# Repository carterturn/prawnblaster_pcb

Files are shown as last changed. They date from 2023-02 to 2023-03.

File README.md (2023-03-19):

Prawnblaster PCB
================

Provides nice panel-mountable BNC connections and ground-isolated USB
for the Prawnblaster (<https://github.com/labscript-suite/prawnblaster>).

Loosely based on <https://github.com/TU-Darmstadt-APQ/Prawnblaster_Breakout>.

-Trigger input is buffered to allow 5V input without risk to Pi Pico.

-Output clocklines are buffered to drive at 5V (and avoid damage to Pi Pico from those lines floating to 5V).

-Clock input is buffered.

-Analog ADuM5000 used for 5V power isolation and Analog ADuM4160 used for USB isolation. Note that speed is fixed at high speed.

-Fits in 1U Bud box (slightly too tall, so upper panel bends slightly, but probably fine).

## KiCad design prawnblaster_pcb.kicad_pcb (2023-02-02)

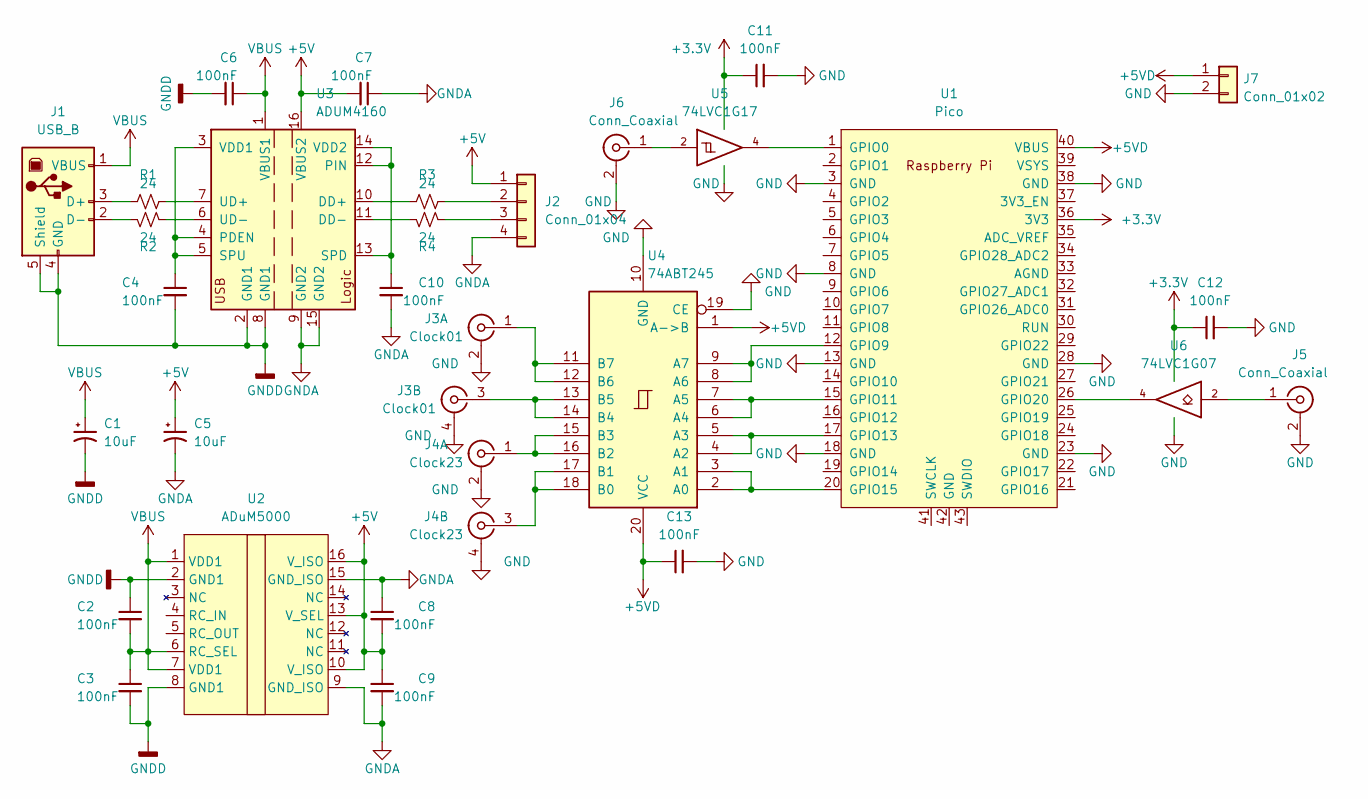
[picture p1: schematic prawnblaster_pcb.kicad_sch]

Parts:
C1, C5: 10uF; CP_Radial_D5.0mm_P2.00mm
C2, C3, C4, C6, C7, C8, C9, C10, C11, C12, C13: 100nF; C_0805_2012Metric
J1: USB_B; USB_B_OST_USB-B1HSxx_Horizontal
J2: Conn_01x04; PinHeader_1x04_P2.54mm_Vertical
J3: Clock01; BNC_Amphenol_031-6575_Horizontal
J4: Clock23; BNC_Amphenol_031-6575_Horizontal
J5, J6: Conn_Coaxial; BNC_Amphenol_B6252HB-NPP3G-50_Horizontal
J7: Conn_01x02; PinHeader_1x02_P2.54mm_Vertical
R1, R2, R3, R4: 24; R_0805_2012Metric
U1: Pico; RPi_Pico_SMD_TH
U2: ADuM5000; SOIC-16W_7.5x10.3mm_P1.27mm
U3: ADUM4160; SOIC-16W_7.5x10.3mm_P1.27mm
U4: 74ABT245; SOIC-20W_7.5x12.8mm_P1.27mm
U5: 74LVC1G17; SOT-23-5_HandSoldering
U6: 74LVC1G07; SOT-23-5_HandSoldering

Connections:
+3.3V: C11.1, C12.1, U1.36 (3V3), U5.5 (VCC), U6.5 (VCC)
+5V: C5.1, C7.2, C8.2, C9.1, J2.1, U2.10 (V_ISO), U2.13 (V_SEL), U2.16 (V_ISO), U3.16 (VBUS2)
+5VD: C13.1, J7.1, U1.40 (VBUS), U4.1 (A->B), U4.20 (VCC)
GND: C11.2, C12.2, C13.2, J3.2 (Ext1), J3.4 (Ext2), J4.2 (Ext1), J4.4 (Ext2), J5.2 (Ext), J6.2 (Ext), J7.2, U1.3 (GND), U1.8 (GND), U1.13 (GND), U1.18 (GND), U1.23 (GND), U1.28 (GND), U1.38 (GND), U4.10 (GND), U4.19 (CE), U5.3 (GND), U6.3 (GND)
GNDA: C5.2, C7.1, C8.1, C9.2, C10.2, J2.4, U2.9 (GND_ISO), U2.15 (GND_ISO), U3.9 (GND2), U3.15 (GND2)
GNDD: C1.2, C2.1, C3.2, C4.2, C6.2, J1.4 (GND), J1.5 (Shield), U2.2 (GND1), U2.8 (GND1), U3.2 (GND1), U3.8 (GND1)
unnamed: C4.1, U3.3 (VDD1), U3.4 (PDEN), U3.5 (SPU)
unnamed: C10.1, U3.12 (PIN), U3.13 (SPD), U3.14 (VDD2)
unnamed: J1.2 (D-), R2.1
unnamed: J1.3 (D+), R1.1
unnamed: J2.2, R3.2
unnamed: J2.3, R4.2
unnamed: J5.1 (In), U6.2
unnamed: J6.1 (In), U5.2
unnamed: R1.2, U3.7 (UD+)
unnamed: R2.2, U3.6 (UD-)
unnamed: R3.1, U3.10 (DD+)
unnamed: R4.1, U3.11 (DD-)
unnamed: U1.1 (GPIO0), U5.4
unnamed: U1.12 (GPIO9), U4.8 (A6), U4.9 (A7)
unnamed: U1.15 (GPIO11), U4.6 (A4), U4.7 (A5)
unnamed: U1.17 (GPIO13), U4.4 (A2), U4.5 (A3)
unnamed: U1.20 (GPIO15), U4.2 (A0), U4.3 (A1)
unnamed: U1.26 (GPIO20), U6.4
unnamed: J3.1 (In1), U4.11 (B7), U4.12 (B6)
unnamed: J3.3 (In2), U4.13 (B5), U4.14 (B4)
unnamed: J4.1 (In1), U4.15 (B3), U4.16 (B2)
unnamed: J4.3 (In2), U4.17 (B1), U4.18 (B0)
VBUS: C1.1, C2.2, C3.1, C6.1, J1.1 (VBUS), U2.1 (VDD1), U2.6 (RC_SEL), U2.7 (VDD1), U3.1 (VBUS1)

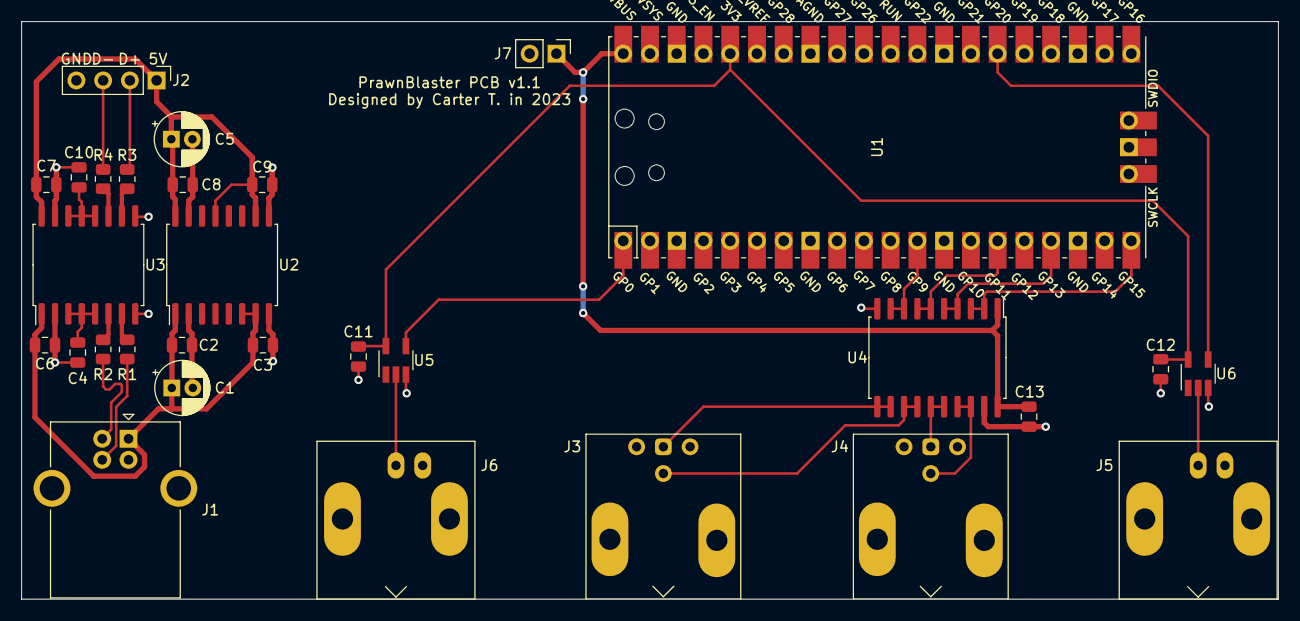
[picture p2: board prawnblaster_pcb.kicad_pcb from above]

Board: 2 copper layers, 119.4 x 54.9 mm, 30 parts (0 on the bottom side), 29 nets.

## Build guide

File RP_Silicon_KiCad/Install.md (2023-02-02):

# Install KiCad libraries

## Manage Symbol Libraries

Accessed from the Preferences menu, add a new line with the +, give it a name and use the folder icon to point to the directory/folder where you have KiCadLibraries.

Manage Symbol Libraries screen shot


## Manage Footprint Libraries

Ditto! Accessed from the Preferences menu, add a new line with the +, give it a name and use the folder icon to point to the directory/folder where you have KiCadLibraries.

Manage Footprint Libraries screen shot


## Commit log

2023-02-02 Initial commit, manufactured as v1.
    USB isolation and trigger output work
    [prawnblaster_pcb.kicad_pcb, prawnblaster_pcb.kicad_sch]
2023-02-02 Fixed trigger plug wiring
    [prawnblaster_pcb.kicad_pcb, prawnblaster_pcb.kicad_sch]
2023-02-02 Updated version number. Now 1.1
    [prawnblaster_pcb.kicad_pcb]
